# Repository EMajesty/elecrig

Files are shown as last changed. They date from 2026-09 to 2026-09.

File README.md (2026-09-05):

# Elecrig

Elecrig is an open hardware system for building pedalboards and other music rigs from standard 20-series aluminium extrusion.

The first interface, **Elecrig Rail 80 (ER80)**, uses parallel rails on an 80 mm pitch with standard M5 T-slot hardware.

## What can you build?

- pedalboards in different sizes
- pedal and device mounts
- upper tiers
- cable management
- I/O panels
- stands, cases and other accessories
- whatever you can think of

## Make stuff

**Building a board?**  
See [`reference-builds/`](reference-builds/).

**Designing a pedal mount or accessory?**  
Start with [`cad/templates/`](cad/templates/) and read the [ER80 specification](spec/ER80.md). Use [`scripts/new-addition.sh`](scripts/new-addition.sh) to scaffold a new device adapter, or manually copy an existing device to edit.

**Want to contribute?**  
See [`CONTRIBUTING.md`](CONTRIBUTING.md).

## Project status

Elecrig is currently experimental.

## License

Open hardware under **CERN-OHL-2.0-W**.

See [`docs/licensing.md`](docs/licensing.md) for details.

# WHERE ARE THE DOWNLOADS???

Here:

[Coming soon]

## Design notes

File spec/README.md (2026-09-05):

# Specifications

This directory contains Elecrig's mechanical interface specifications.

- [`ER80.md`](ER80.md) — Elecrig Rail 80

Specifications define compatibility. Reference builds are examples, not rules.

If you want to propose a change to a stable interface, open an issue first and
describe the use case, compatibility impact, and any relevant prototype or CAD.

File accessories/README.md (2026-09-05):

# Accessories

General Elecrig accessories belong here.

Examples:

- cable clips
- tier supports
- hinged deck hardware
- handles
- feet
- I/O panels
- case parts
- stands

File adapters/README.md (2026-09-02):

# Device adapters

Device-specific mounts belong here.

Each adapter should include a short README with compatibility, required
hardware, target Elecrig version, and physical verification status.

See [`README-TEMPLATE.md`](README-TEMPLATE.md).

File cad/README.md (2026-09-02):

# CAD

- `interfaces/` — canonical Elecrig interface geometry
- `templates/` — starter models for new compatible parts

Use STEP as the preferred neutral exchange format.

Native/editable CAD may also be provided where redistribution permits it.

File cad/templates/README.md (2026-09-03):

# CAD templates

Starter models for designing Elecrig-compatible hardware belong here.

Planned templates include:

- pedal/device adapter blank
- generic rail accessory blank
- side/end accessory blank
- tier support blank

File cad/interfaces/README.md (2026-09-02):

# Interface geometry

Canonical neutral CAD for Elecrig interfaces belongs here.

These files should contain only the geometry needed to design compatible parts,
not complete reference assemblies.

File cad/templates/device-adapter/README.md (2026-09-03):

# Device adapter template

Starting geometry for ER80 device adapters.

## Onshape template

[Open the editable template in Onshape](https://cad.onshape.com/documents/fb0dd42ad10a1523afac7c45/w/2e96b723ed7283d5c78a0a61/e/b73b7ce0a00f62bfe81d42b5)

Make a copy of the document, set `rail_span`, then edit the `EDIT_ME` sketch to connect the mounting tabs to your device.

The template provides:

- 80 mm rail spacing
- 20 mm slot spacing
- 5.2 mm mounting holes
- 12 × 12 mm mounting tabs
- calculated inner and outer mounting positions
- adjustable rail span

For devices spanning two or more rails, the recommended convention is:

- left adapter: outer mounting positions
- right adapter: inner mounting positions

This is a recommendation, not a requirement.

## Other CAD software

`device-adapter.dxf` contains the template sketch for use outside Onshape.

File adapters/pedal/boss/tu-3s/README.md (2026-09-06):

# Boss TU-3S

Elecrig mount for the Boss TU-3S.

Mounted device

## Compatibility

- **Device:** Boss TU-3S
- **Interface:** ER80
- **Rail span:** [1 / 2 / 3 / other]
- **Tested:** [Yes / No]

## Hardware

**Device attachment:** [Original screws / Replacement screws / Other]  
**Rubber feet:** [Keep / Remove / N/A]

### Additional device hardware

- [e.g. 4 × M3×12 screws]
- None

### Rail hardware

- [e.g. 4 × M5×10 bolts]
- [e.g. 4 × M5 hammer nuts]

## Files

- `cad/` — STEP files
- `print/` — ready-to-print 3MF files
- `images/` — reference and installation photos

## Printing

**Material:** [e.g. PETG]  
**Supports:** [Yes / No]

[Only add additional print notes when necessary.]

## Installation

[Brief device-specific installation instructions. Mention screw replacement,
feet removal, orientation, or anything else that isn't obvious.]

## CAD

[Onshape link, if available]

## Notes

[Optional compatibility notes, limitations, alternate models, etc.]

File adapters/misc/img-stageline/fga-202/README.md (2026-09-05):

# IMG Stageline FGA-202

Elecrig mount for the IMG Stageline FGA-202.

Mounted device

## Compatibility

- **Device:** IMG Stageline FGA-202
- **Interface:** ER80
- **Rail span:** 2
- **Tested:** Yes

## Hardware

**Device attachment:** Original screws  
**Rubber feet:** Remove

### Additional device hardware

- None

### Rail hardware

- 4 × M5×10 bolts
- 4 × M5 hammer nuts

## Files

- `cad/` — STEP files
- `print/` — ready-to-print 3MF files
- `images/` — reference and installation photos

## Printing

**Material:**
**Supports:**

## Installation

Remove rubber feet, then attach the brackets with the original screws

## CAD

https://cad.onshape.com/documents/e6d982047e9a278fe3f14910/w/8a50545e375b66e950502b89/e/bf507b35f82c9b6e82056bd3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

## Notes

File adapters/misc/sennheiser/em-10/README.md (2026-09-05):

# Sennheiser EM 10

Elecrig mount for the Sennheiser EM 10.

Mounted device

## Compatibility

- **Device:** Sennheiser EM 10
- **Interface:** ER80
- **Rail span:** 2
- **Tested:** [Yes / No]

## Hardware

**Device attachment:** Additional bolts  
**Rubber feet:** Keep

### Additional device hardware

- 4 × M3×8

### Rail hardware

- 4 × M5×10 bolts
- 4 × M5 hammer nuts

## Files

- `cad/` — STEP files
- `print/` — ready-to-print 3MF files
- `images/` — reference and installation photos

## Printing

**Material:**
**Supports:**

## Installation

Installs horizontally, in any orientation since the mounting holes in the receiver are spaced the same and mirrored on the top/bottom

## CAD

https://cad.onshape.com/documents/e6d982047e9a278fe3f14910/w/8a50545e375b66e950502b89/e/c9836fe8b54f796db6128102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

## Notes

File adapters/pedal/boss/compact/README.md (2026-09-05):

# Boss Compact

Elecrig mount for the Boss Compact.

Mounted device

## Compatibility

- **Device:** Boss Compact
- **Interface:** ER80
- **Rail span:** 2
- **Tested:** Yes

## Hardware

**Device attachment:** Original screws  
**Rubber feet:** Remove

### Additional device hardware

- None

### Rail hardware

- 4 × M5×10 bolts
- 4 × M5 hammer nuts

## Files

- `cad/` — STEP files
- `print/` — ready-to-print 3MF files
- `images/` — reference and installation photos

## Printing

**Material:**
**Supports:**

## Installation

Remove rubber pad from bottom plate. Version that supports leaving the rubber pad on later

## CAD

https://cad.onshape.com/documents/e6d982047e9a278fe3f14910/w/8a50545e375b66e950502b89/e/7a75be1224cae9167ae28804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

## Notes

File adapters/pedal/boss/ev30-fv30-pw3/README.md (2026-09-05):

# Boss EV-30 FV-30 PW-3

Elecrig mount for the Boss EV-30 FV-30 PW-3.

Mounted device

## Compatibility

- **Device:** Boss EV-30 FV-30 PW-3
- **Interface:** ER80
- **Rail span:** 3
- **Tested:** Yes

## Hardware

**Device attachment:** Original screws  
**Rubber feet:** Remove

### Additional device hardware

- None

### Rail hardware

- 4 × M5×10 bolts
- 4 × M5 hammer nuts

## Files

- `cad/` — STEP files
- `print/` — ready-to-print 3MF files
- `images/` — reference and installation photos

## Printing

**Material:**
**Supports:**

## Installation

## CAD

https://cad.onshape.com/documents/e6d982047e9a278fe3f14910/w/8a50545e375b66e950502b89/e/91eb7fc5b8587d6b223b5cd1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

## Notes

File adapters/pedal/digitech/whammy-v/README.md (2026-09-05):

# Digitech Whammy V

Elecrig mount for the Digitech Whammy V.

Mounted device

## Compatibility

- **Device:** Digitech Whammy V
- **Interface:** ER80
- **Rail span:** 3
- **Tested:** Yes

## Hardware

**Device attachment:** Original screws  
**Rubber feet:** Remove

### Additional device hardware

- None

### Rail hardware

- 4 × M5×10 bolts
- 4 × M5 hammer nuts

## Files

- `cad/` — STEP files
- `print/` — ready-to-print 3MF files
- `images/` — reference and installation photos

## Printing

**Material:**
**Supports:**

Lay mount pieces flat on the bed

## Installation

Install mount pieces under the top panel bolts

## CAD

https://cad.onshape.com/documents/e6d982047e9a278fe3f14910/w/8a50545e375b66e950502b89/e/7ee868753980821126ad0568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

## Notes

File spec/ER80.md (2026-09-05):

# Elecrig Rail 80 (ER80)

ER80 is the basic rail layout used by Elecrig.

## Rails

ER80 uses standard metric **2040 T-slot extrusion**, laid flat:

- 40 mm wide
- 20 mm high
- M5 T-slot hardware
- rail ends tapped M6

## Spacing

Rails are spaced **80 mm center-to-center**.

For example:

| Rails | Center positions | Overall rail depth |
|---:|---|---:|
| 2 | 0, 80 mm | 120 mm |
| 3 | 0, 80, 160 mm | 200 mm |
| 4 | 0, 80, 160, 240 mm | 280 mm |

More rails simply continue the same 80 mm spacing.

## Rail ends

Each 2040 rail has two **M6 threaded mounting holes** at each end.

These can be used for side panels and other end-mounted accessories.

See the ER80 drawing for exact positions.

## Compatible parts

An ER80-compatible part should fit any correctly spaced ER80 rail set without depending on a particular board width or side-panel design.

That's it!

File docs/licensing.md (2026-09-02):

# Licensing

Elecrig uses different licences for different kinds of source.

## Hardware source

The following are licensed under the **CERN Open Hardware Licence Version 2 –
Weakly Reciprocal**, SPDX identifier **`CERN-OHL-2.0-W`**:

- `spec/`
- `cad/`
- `reference-builds/`
- `adapters/`
- `accessories/`

The canonical licence text lives in:

`LICENSES/CERN-OHL-2.0-W.txt`

## Documentation

Content in `docs/` is licensed under **CC BY-SA 4.0**.

## Software

Software in `software/` is licensed under **MIT** unless stated otherwise.

## SPDX identifiers

Where practical, use:

```text
SPDX-License-Identifier: CERN-OHL-2.0-W
SPDX-License-Identifier: CC-BY-SA-4.0
SPDX-License-Identifier: MIT
```

For CAD formats that do not support convenient source comments, put the licence
information in a README in the same directory.

Do not modify the licence texts themselves.

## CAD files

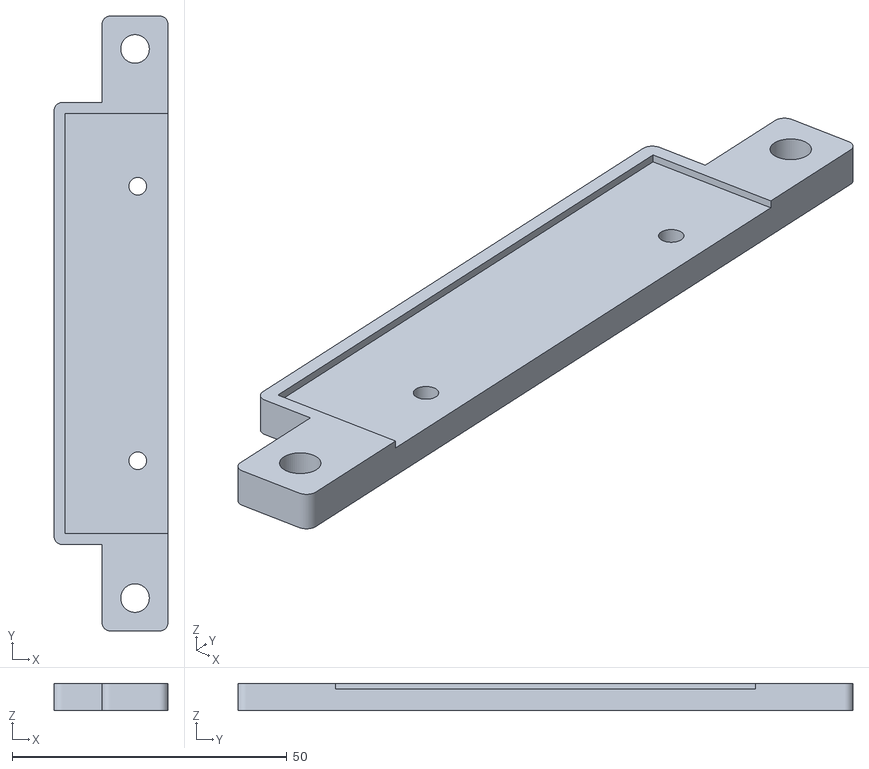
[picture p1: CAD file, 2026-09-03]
adapters/misc/img-stageline/fga-202/print/IMG Stageline FGA-202 - left.stl
20.8 x 112.0 x 5.00

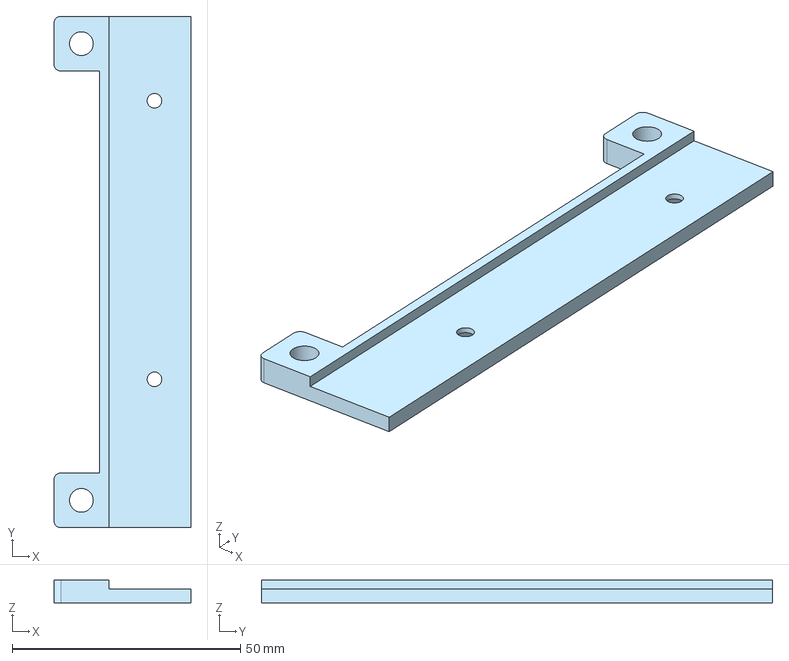
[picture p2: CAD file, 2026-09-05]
adapters/misc/sennheiser/em-10/cad/Sennheiser EM 10 - left.step
30.0 x 112.0 x 5.00 mm

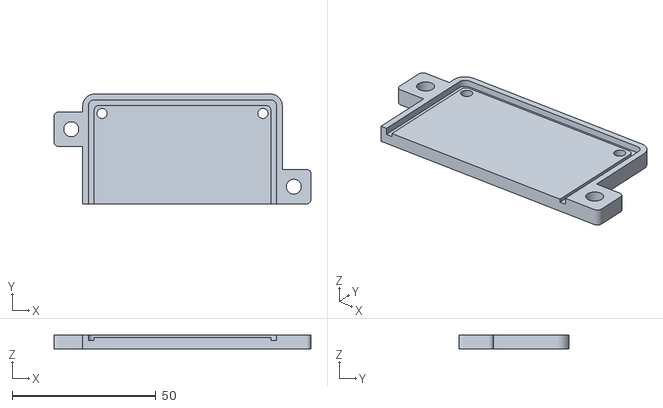
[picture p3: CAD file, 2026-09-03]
adapters/pedal/boss/compact/print/Boss Compact - top.stl
89.5 x 38.2 x 5.00

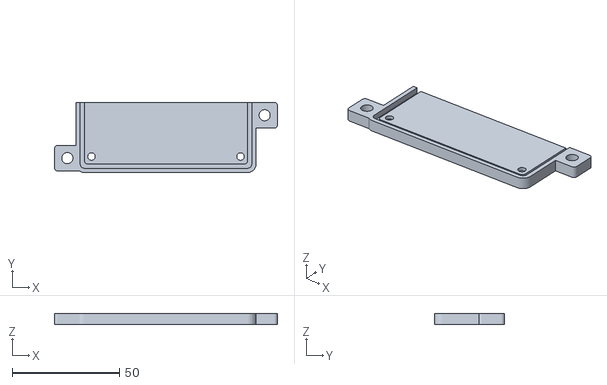
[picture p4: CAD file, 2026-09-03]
adapters/pedal/boss/ev30-fv30-pw3/print/Boss EV-30 FV-30 PW-3 - bottom.stl
104.0 x 32.8 x 5.00

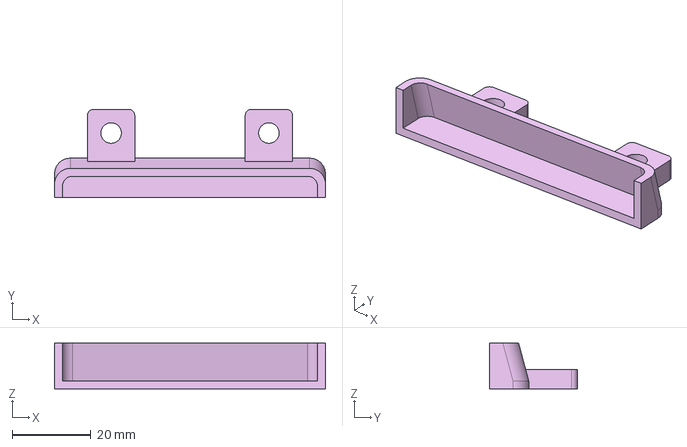
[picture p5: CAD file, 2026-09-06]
adapters/pedal/boss/tu-3s/cad/Boss TU-3S - top.step
68.7 x 22.4 x 11.7 mm

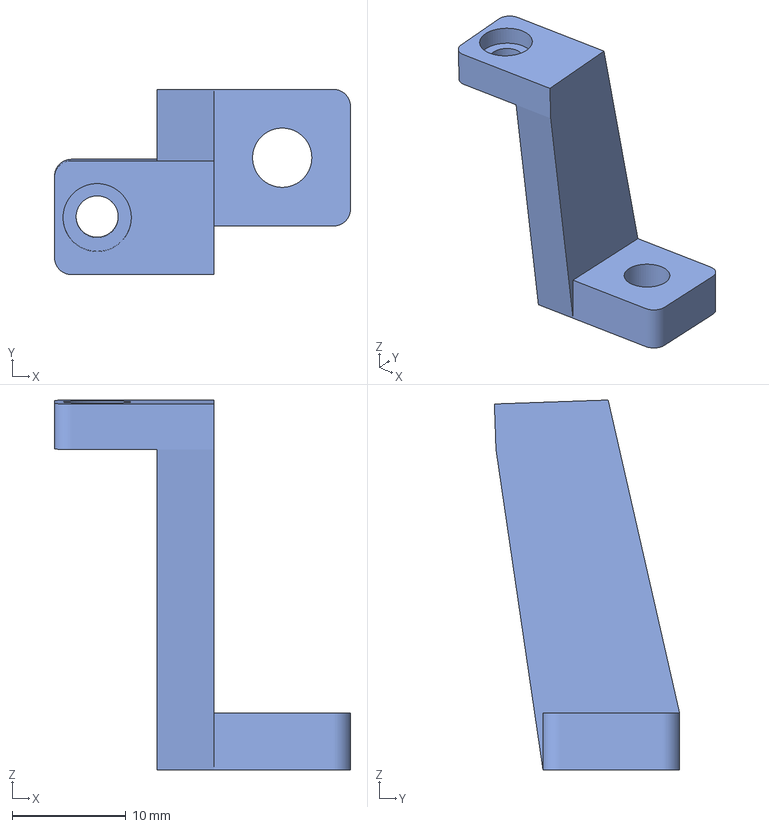
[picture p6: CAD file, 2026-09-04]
adapters/pedal/digitech/whammy-v/print/Digitech Whammy V - bottom-right.3mf
26.0 x 16.3 x 32.5 mm

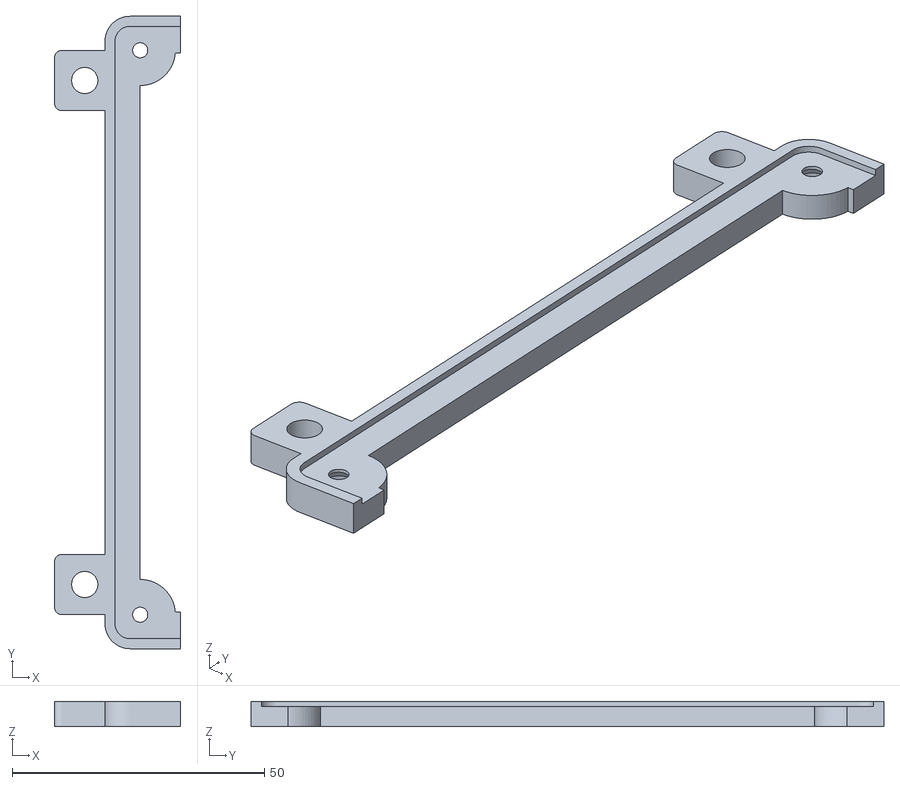
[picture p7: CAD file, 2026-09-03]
adapters/pedal/eventide/space/print/Eventide Space - left.stl
25.0 x 125.5 x 5.00

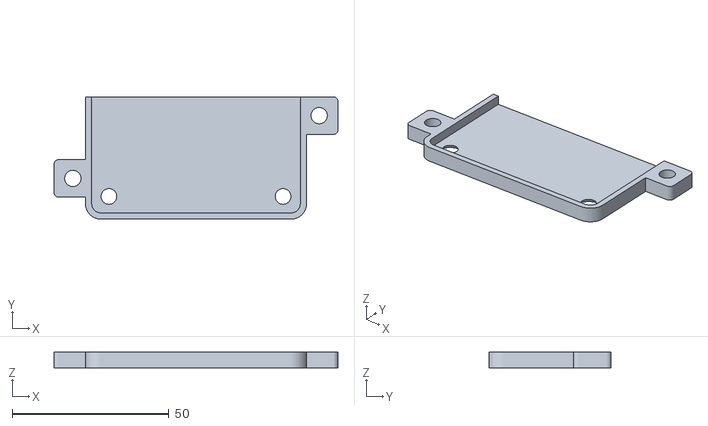
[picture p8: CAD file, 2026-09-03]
adapters/pedal/hammond/125b/print/Hammond 125B Vertical - bottom.stl
90.5 x 39.0 x 5.00

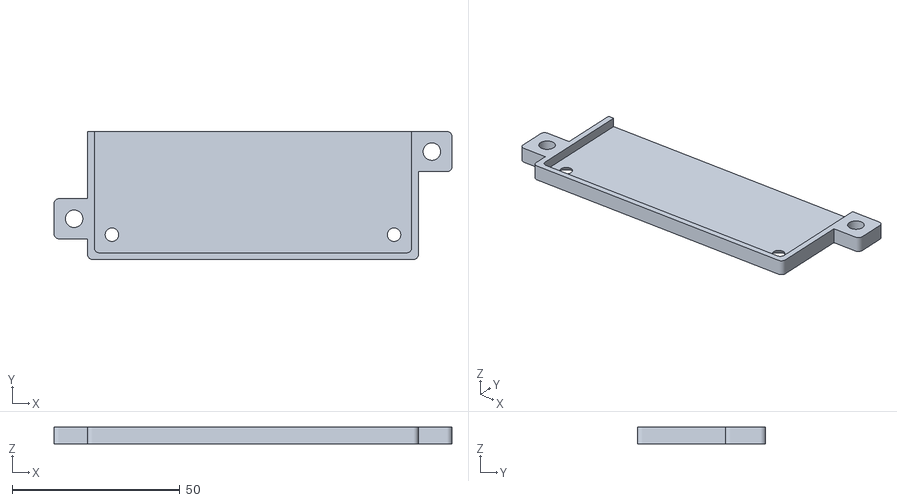
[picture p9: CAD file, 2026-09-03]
adapters/pedal/hammond/1590bb/print/Hammond 1590BB Vertical - bottom.stl
118.5 x 38.2 x 5.00

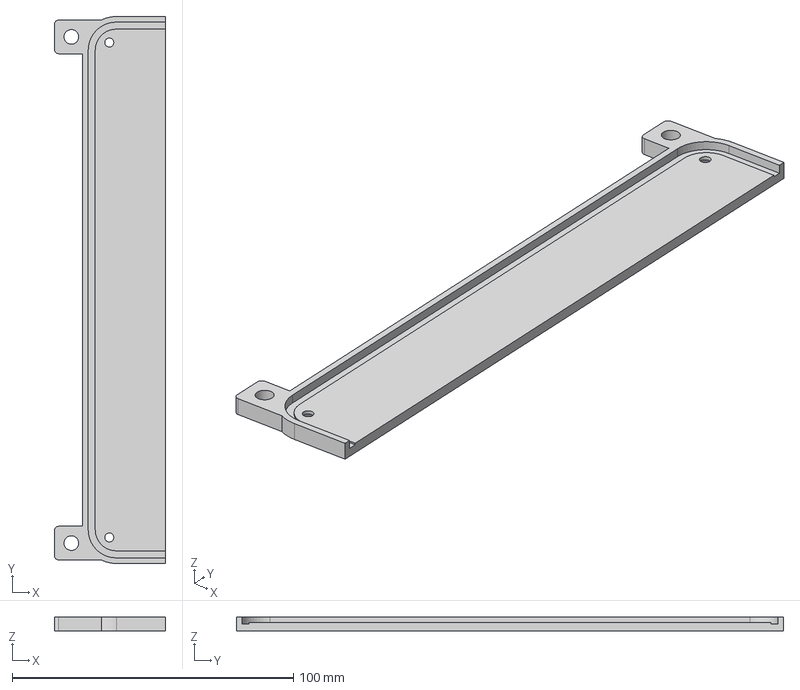
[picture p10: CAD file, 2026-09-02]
adapters/pedal/neural-dsp/quad-cortex/cad/quad-cortex-left.step
39.5 x 194.5 x 5.00 mm

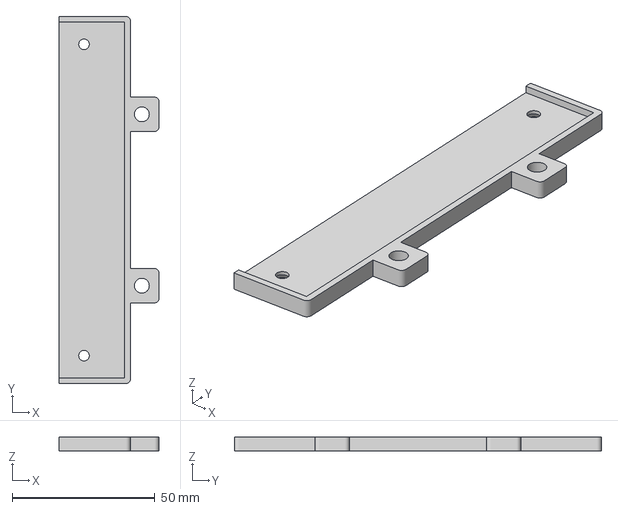
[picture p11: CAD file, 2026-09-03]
adapters/pedal/strymon/timeline/print/Strymon Timeline - right.3mf
35.0 x 128.5 x 5.00 mm

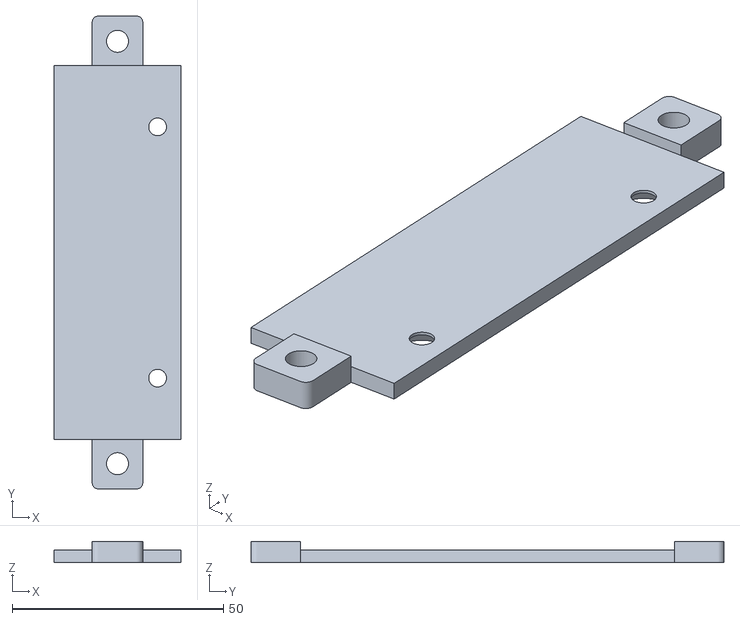
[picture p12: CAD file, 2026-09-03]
adapters/psu/cioks/crux/print/Cioks Crux - plate.stl
30.0 x 112.0 x 5.00

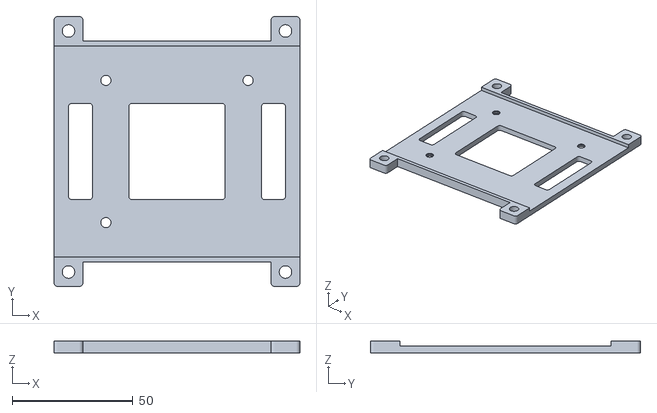
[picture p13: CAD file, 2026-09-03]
adapters/psu/cioks/dc7/print/Cioks DC7 - plate.stl
102.0 x 112.0 x 5.00

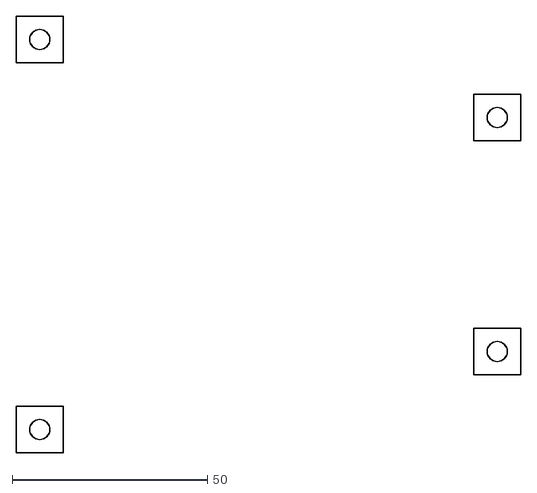
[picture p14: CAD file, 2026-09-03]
cad/templates/device-adapter/device-template.dxf
129.3 x 112.0

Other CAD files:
reference-builds/big - right bottom.3mf
adapters/misc/img-stageline/fga-202/print/IMG Stageline FGA-202 - right.stl
adapters/misc/sennheiser/em-10/cad/Sennheiser EM 10 - right.step
adapters/pedal/boss/compact/print/Boss Compact - bottom.stl
adapters/misc/sennheiser/em-10/print/Sennheiser EM 10 - left.3mf
adapters/misc/sennheiser/em-10/print/Sennheiser EM 10 - right.3mf
adapters/pedal/boss/ev30-fv30-pw3/print/Boss EV-30 FV-30 PW-3 - top.stl
adapters/pedal/boss/tu-3s/cad/Boss TU-3S - bottom.step
adapters/pedal/boss/tu-3s/print/Boss TU-3S - bottom.3mf
adapters/pedal/boss/tu-3s/print/Boss TU-3S - top.3mf
adapters/pedal/digitech/whammy-v/print/Digitech Whammy V - bottom-left.3mf
adapters/pedal/digitech/whammy-v/print/Digitech Whammy V - top-left.3mf
adapters/pedal/digitech/whammy-v/print/Digitech Whammy V - top-right.3mf
adapters/pedal/eventide/space/print/Eventide Space - right.stl
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

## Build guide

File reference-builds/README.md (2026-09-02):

# Reference builds

Complete Elecrig builds belong here.

Reference builds demonstrate practical ways to use the standard, but they are
not normative.

Good starter examples:

- compact 2-rail board
- standard 3-rail board
- larger 4-rail board
- hinged upper-tier build

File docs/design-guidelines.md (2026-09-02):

# Design guidelines

This document is for rationale and best practices that do not belong in the
normative specification.

## Keep the interface small

Elecrig should standardize only what needs to be shared between independently
designed parts.

For example, ER80 should define how a part attaches to the rail system, not how
a two-tier pedalboard must be constructed.

## Prefer reusable interfaces

A pedal adapter, PSU bracket, cable guide, tier support or case part should all
be able to target the same small set of canonical interfaces.

## Design for remixing

Where practical:

- use common metric fasteners
- make mounting positions adjustable
- keep device geometry separate from rail geometry
- release neutral CAD
- document physically tested fit

## Experimental work

New ideas are welcome without changing the core standard.

Mark them clearly as experimental until the interface is mature enough to be
specified.

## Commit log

2026-09-02 Simplify ER80 rail specification
2026-09-02 Document reversible hardware adapter mounting guidelines
2026-09-02 Document Quad Cortex mount and rail spacing convention
2026-09-02 Add left Quad Cortex adapter CAD model
    [quad-cortex-left.3mf, quad-cortex-left.step, quad-cortex-right.3mf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]
2026-09-02 Add adapter template and scaffolding script
    [quad-cortex-left.3mf, quad-cortex-left.step, quad-cortex-right.3mf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]
2026-09-03 Document device adapter scaffolding script
2026-09-03 Add mounts for IMG Stageline and Boss pedals
    [Boss Compact - bottom.stl, Boss Compact - top.stl, Boss EV-30 FV-30 PW-3 - bottom.stl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]
2026-09-03 Add ER80 device adapter CAD template
    [device-template.dxf]
2026-09-03 Document Cioks Crux and DC7 mount hardware
2026-09-04 Add Digitech Whammy V pedal adapter files
    [Digitech Whammy V - bottom-left.3mf, Digitech Whammy V - bottom-right.3mf, Digitech Whammy V - top-left.3mf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]
2026-09-05 Add Sennheiser EM 10 adapter files
    [Sennheiser EM 10 - left.3mf, Sennheiser EM 10 - left.step, Sennheiser EM 10 - right.3mf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]
2026-09-05 Document Sennheiser EM 10 mount hardware and installation
2026-09-05 Document tested mounts and add CAD links
2026-09-05 Update adapter CAD links to specific Onshape models
2026-09-06 Add Boss TU-3S pedal adapter CAD model
    [Boss TU-3S - bottom.3mf, Boss TU-3S - bottom.step, Boss TU-3S - top.3mf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]
2026-09-12 Update Boss TU-3S print models
    [Boss TU-3S - bottom.3mf, Boss TU-3S - top.3mf]
